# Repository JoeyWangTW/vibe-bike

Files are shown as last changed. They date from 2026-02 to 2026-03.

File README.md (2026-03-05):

# Vibe Bike

**What do humans do while agents work? They bike.**

Turn a broken indoor bike into a smart training station. Track cadence, speed, heart rate, and Claude Code token spend — all on one ESP32 display.

Built as a vibe coding project with Claude Code.

## Features

- **Cadence & speed** from the bike's built-in reed switch sensor
- **Distance tracking** with session auto-detect (start/stop)
- **BLE heart rate** from any Bluetooth heart rate strap
- **Claude Code stats** — live output tokens and message count from your coding sessions
- **SD card logging** — CSV session logs with full ride data
- **3D-printable mount** to attach the display to the bike

## Hardware

| Part | Notes |
|---|---|
| ESP32 CYD (Cheap Yellow Display) | 2.8" ESP32-32E with ILI9341, 240x320px. [Amazon](https://www.amazon.com/dp/B0G1M5XHDL) (or cheaper on AliExpress, search "ESP32-2432S028") |
| Indoor bike with reed switch | Most indoor bikes have a 2-pin magnetic reed switch for cadence. If yours doesn't, any hall effect sensor works |
| BLE heart rate strap | Any strap that advertises BLE Heart Rate Service (UUID 0x180D). Tested with Coospo H808S |
| 10K resistor | Pull-up for the reed switch signal line |
| Micro SD card | For session logging (optional) |
| 3D-printed mount | See `3d-model/` — slots onto a metal plate bracket on the bike |

### Wiring

The reed switch connects to GPIO 35 with a pull-up resistor:

```
3.3V ─── 10K resistor ─── IO35 ─── bike wire 1
GND  ────────────────────────────── bike wire 2
```

No polarity — the reed switch is just an open/close contact.

## Setup

### 1. Install arduino-cli

```bash
# macOS
brew install arduino-cli

# Or see https://arduino.github.io/arduino-cli/installation/
```

### 2. Install ESP32 board support

```bash
arduino-cli config init
arduino-cli config add board_manager.additional_urls https://raw.githubusercontent.com/espressif/arduino-esp32/gh-pages/package_esp32_index.json
arduino-cli core update-index
arduino-cli core install esp32:esp32@3.3.7
```

### 3. Install libraries

```bash
arduino-cli lib install "TFT_eSPI@2.5.43"
arduino-cli lib install "ArduinoJson@7.4.2"
```

The TFT_eSPI library needs its `User_Setup.h` configured for the CYD's ILI9341 SPI pins. See the [display docs](https://www.lcdwiki.com/2.8inch_ESP32-32E_Display) for pin mapping.

### 4. Configure

```bash
cd firmware/bike_dashboard
cp config.example.h config.h
```

Edit `config.h`:

```c
// WiFi (optional — leave empty to skip)
#define WIFI_SSID         "your-wifi"
#define WIFI_PASSWORD     "your-password"

// Claude Code stats server (optional — leave empty to skip)
#define STATS_SERVER_IP   "192.168.1.100"
#define STATS_SERVER_PORT  8888

// BLE heart rate strap name (optional — leave empty to match any HR device)
#define BLE_HR_DEVICE_NAME  "808"
```

All three sections are optional. The dashboard works standalone with just the bike sensor.

### 5. Compile and upload

```bash
# Compile (min_spiffs partition needed for BLE + WiFi)
arduino-cli compile -b esp32:esp32:esp32:PartitionScheme=min_spiffs firmware/bike_dashboard

# Upload (460800 baud — default 921600 fails on CYD boards)
arduino-cli upload -b esp32:esp32:esp32:PartitionScheme=min_spiffs,UploadSpeed=460800 -p /dev/cu.usbserial-1120 firmware/bike_dashboard
```

Your serial port will differ — run `arduino-cli board list` to find it. The CYD uses a CH340 USB-serial chip.

If upload fails with "Failed to connect to ESP32", hold the **BOOT** button on the board while uploading.

### 6. Claude Code stats server (optional)

To show live Claude Code token usage on the display:

```bash
python3 scripts/stats_server.py
```

This reads your local Claude Code session data and serves it over HTTP. The ESP32 polls it every 30 seconds. The server prints the IP and port to put in your `config.h`.

## 3D-Printable Mount

The `3d-model/` directory has OpenSCAD source and ready-to-print STL files:

- **`bike_mount.scad`** — Tray-style case. The board slides in from the front, 4 L-bracket corner spacers hold it at the right depth with space behind for a battery. A slot in the back wall friction-fits onto a metal plate bracket on the bike. USB-C accessible from the bottom.
- **`front_cap.scad`** — Snap-on faceplate with a screen cutout. Covers the PCB edges, shows only the display.

Print with the open face pointing up. No supports needed.

## Project Structure

```
firmware/
  bike_dashboard/         # Main dashboard firmware
    bike_dashboard.ino
    config.example.h      # Template — copy to config.h
  test_ble_hr/            # BLE heart rate test sketch
  test_ble_scan/          # BLE scan test sketch
  test_reed_switch/       # Reed switch test sketch
  hello_world/            # Display test sketch

scripts/
  stats_server.py         # Claude Code stats HTTP bridge

3d-model/
  bike_mount.scad         # Display mount (OpenSCAD source)
  bike_mount.stl          # Ready to print
  front_cap.scad          # Front cap (OpenSCAD source)
  front_cap.stl           # Ready to print
```

## License

MIT

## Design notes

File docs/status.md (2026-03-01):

# Project Status

**Last updated:** 2026-03-01

**Current state:** Phase 3 COMPLETE + HR Zone feature. Full vibe bike dashboard with cadence, speed, distance, BLE heart rate, Claude Code stats tracking, SD logging, and touchscreen HR zone settings.

## Recently Completed

- **HR Zone feature** — touchscreen-enabled heart rate zone settings
  - XPT2046_Bitbang touch on software SPI (IO32/39/25/33, IRQ on IO36)
  - Page system: dashboard ↔ HR zone settings (tap HR block to open)
  - Settings: upper/lower limit +/- (5 bpm steps), on/off toggle, back button
  - Zone indicator: green background in-zone, flashing red out-of-zone
  - NVS persistence via Preferences library (survives reboots)
  - Flash: 1892KB (96% of min_spiffs), 74KB headroom
- **Phase 1** (VB-001 to VB-009): Pulse counting, RPM, speed, distance, TFT dashboard, session management, SD logging
- **Phase 2** (VB-010 to VB-013): BLE heart rate from Coospo H808S chest strap
- **Phase 3** (VB-014 to VB-017): WiFi + Claude Code stats tracking

## Technical Notes

- Partition scheme: `min_spiffs` (BLE+WiFi needs ~1.8MB flash vs 1.3MB default)
- BLE: Uses **built-in ESP32 BLE** (NOT NimBLE — NimBLE 2.3.7 scan returns 0 devices on this board)
- HR strap: Coospo H808S, advertises as "808S 0023713", BLE address `de:5c:38:c5:83:1d`
- Stats tracking reads `~/.claude/stats-cache.json` via local Python HTTP bridge (not Anthropic Admin API, which tracks API billing not Max subscription)
- WiFi and stats tracking are optional — leave `WIFI_SSID` and `STATS_SERVER_IP` empty to disable
- Upload baud: 460800 (921600 causes "chip stopped responding")

## In Progress

- (Nothing currently in progress)

## Up Next

- Upload and test touch calibration (first boot will prompt calibration via Serial)
- Test HR zone settings page on device
- Physical mounting of display on bike
- Test full end-to-end: pedal + HR strap + stats server + HR zones

## Blockers

- (none)

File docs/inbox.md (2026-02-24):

# Inbox

Action items from co-founder discussions, standups, and meetings appear here.
Mark items as `[SEEN]` after reading them.

---

## From VP Cadence Cole Planning Session (2026-02-24)

- [x] [DONE] Probe the bike's 2-pin connector with a multimeter. Result: reed switch, 1 pulse/rev, no polarity.
- [ ] Power up the ESP32 display board and verify it works. Try a simple TFT_eSPI example sketch.
- [ ] [SEEN] Test IO35 with a simple digitalRead — confirmed plan: IO35 with 10K pull-up. Use `firmware/test/test_reed_switch.cpp` to verify.
- [ ] Measure the physical mounting: how will the display attach where the old monitor was? Any 3D printing needed or can you use zip ties / velcro for now?
- [ ] Check your chest HR strap model — confirm it supports standard BLE Heart Rate Service (UUID 0x180D). Most Garmin/Polar/Wahoo straps do.

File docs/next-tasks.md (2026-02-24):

# Prioritized Tasks

## Completed
- ~~**VB-001:** Probe 2-pin connector~~ — reed switch, 1 pulse/rev
- ~~**VB-002:** Test GPIO~~ — IO35 confirmed
- ~~**VB-003:** Wire bike sensor~~ — IO35 + 10K pull-up + GND

## Next Up (Phase 1 Firmware)

1. **VB-006:** Set up PlatformIO project, configure TFT_eSPI for the ILI9341 board, flash "Hello World"
2. **VB-004:** Implement interrupt-driven pulse counter (use `test_reed_switch.cpp` to verify hardware first)
3. **VB-005:** Calculate speed and distance from RPM
4. **VB-007:** Build dashboard UI v1 (RPM, speed, distance, time)
5. **VB-008:** Auto-detect session start/stop
6. **VB-009:** Log session data to SD card

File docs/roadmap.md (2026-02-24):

# Vibe Bike Roadmap

## Vision

**"What do humans do while agents work? Joey bikes."**

Vibe Bike is a personal fitness-meets-vibe-coding dashboard. It turns a broken indoor bike into a smart training station that tracks physical activity AND coding productivity in one place. The final form is a "vibe coding bike session" — pedal, monitor heart rate, and watch your Claude Code token spend all on a single ESP32 display mounted where the old monitor used to be.

The deeper message: while AI agents handle the code, you invest in yourself. Get healthier, stay sharp, and still see exactly what your agents are burning through.

## Hardware

| Component | Details |
|---|---|
| Indoor bike | Broken monitor removed; 2-pin connector exposed (likely reed switch for cadence/speed) |
| Display/MCU | 2.8" ESP32-32E (ILI9341V), 240x320px, ESP32-D0WD-V3 dual-core @ 240MHz |
| Connectivity | WiFi 802.11b/g/n, Bluetooth 4.2 + BLE |
| Heart rate | Chest strap (BLE-compatible, likely ANT+ too) |
| Free GPIOs | IO27 (if SPI peripheral unused), IO35 (input-only) — very limited |

---

## Phase 1: Bike Data on Screen (MVP)

**Goal:** Read cadence/speed from the bike's 2-pin connector and display it on the ESP32 screen.

**Timeline:** 1-2 weeks

### Milestones

- [ ] **1.1 — Hardware investigation**
  - Probe the 2-pin connector with a multimeter to determine signal type (reed switch pulses vs. analog vs. hall effect)
  - Identify a usable GPIO on the ESP32 board (IO27 or IO35 are candidates)
  - Wire the 2-pin connector to the ESP32 with appropriate pull-up/pull-down resistor

- [ ] **1.2 — Signal capture firmware**
  - Write interrupt-driven pulse counter on ESP32 (Arduino or ESP-IDF)
  - Calculate RPM from pulse timing
  - Estimate speed/distance using assumed wheel circumference

- [ ] **1.3 — Display UI v1**
  - Render a simple dashboard on the ILI9341: current RPM, speed, distance, elapsed time
  - Use TFT_eSPI or LovyanGFX library for rendering
  - Keep it clean — big numbers, easy to read while pedaling

- [ ] **1.4 — Session persistence**
  - Log session data to ESP32's onboard SD card (CSV format)
  - Start/stop session with a simple trigger (e.g., first pedal stroke starts, 30s idle stops)

### Key Risks
- **GPIO scarcity:** The ESP32 board has very few free pins. IO35 is input-only (fine for reading pulses). IO27 may conflict with SPI. Need to verify on actual hardware.
- **Signal type unknown:** The 2-pin connector might be a simple reed switch (most likely), but could also be a hall sensor with specific voltage needs.
- **No physical button:** Starting/stopping sessions may need to be auto-detected from pedal activity.

---

## Phase 2: Heart Rate Monitor

**Goal:** Connect BLE chest strap and add heart rate to the dashboard.

**Timeline:** 1-2 weeks (after Phase 1)

### Milestones

- [ ] **2.1 — BLE heart rate pairing**
  - Implement BLE client on ESP32 to scan and connect to heart rate strap
  - Use standard Heart Rate Service (UUID 0x180D) / Heart Rate Measurement Characteristic (0x2A37)
  - Handle reconnection gracefully

- [ ] **2.2 — Display UI v2**
  - Add heart rate (current BPM) to the dashboard
  - Add heart rate zone indicator (zone 1-5 based on estimated max HR)
  - Show connection status for the HR strap

- [ ] **2.3 — Combined session logging**
  - Merge cadence + HR data into session logs
  - Timestamp alignment between bike pulses and HR readings

### Key Risks
- **BLE + WiFi coexistence:** ESP32 shares the radio between WiFi and BLE. If both are active, performance may degrade. Phase 2 is BLE-only so this is fine, but matters for Phase 3.
- **HR strap compatibility:** Most chest straps support standard BLE HR profile, but some cheaper ones may not.

---

## Phase 3: Vibe Coding Dashboard

**Goal:** Track Claude Code token usage alongside bike + HR data. The ultimate "vibe coding session" view.

**Timeline:** 2-4 weeks (after Phase 2)

### Milestones

- [ ] **3.1 — Claude Code token tracking**
  - Build a lightweight local service (Python or Node) that monitors Claude Code token usage
  - Options: parse Claude Code logs, use API usage endpoints, or intercept billing data
  - Expose a simple HTTP endpoint on the local machine for the ESP32 to poll

- [ ] **3.2 — WiFi data sync**
  - Connect ESP32 to local WiFi
  - Poll the token tracking endpoint periodically (every 30s)
  - Handle WiFi + BLE coexistence (may need to time-slice or alternate)

- [ ] **3.3 — Display UI v3 — Final Form**
  - Combined dashboard: cadence, speed, distance, time, HR, HR zone, tokens used, cost
  - Session summary screen at end of ride
  - Maybe: a fun "vibe score" combining physical effort + code productivity

- [ ] **3.4 — Session history and trends**
  - Daily session logs: duration, distance, avg HR, tokens used
  - Upload session data to a simple local DB or flat files for trend viewing
  - Optional: a simple web dashboard for historical data

### Key Risks
- **Token tracking API:** Claude Code may not expose usage data in a clean, parseable way. May need to get creative with log parsing.
- **WiFi + BLE conflict:** Both use the same radio. May need to alternate connections or use BLE for HR and WiFi in bursts.
- **Scope creep:** This phase could grow endlessly. Keep the MVP tight: just show tokens used in current session.

---

## Future Ideas (Post-V1)

- **Leaderboard / streaks:** Track daily riding streaks and coding output
- **Agent health check:** Show which Claude Code tasks are running while you ride
- **Calorie-to-token ratio:** A fun metric — how many calories per 1K tokens?
- **OTA updates:** Push firmware updates over WiFi so you don't have to dismount
- **3D-printed enclosure:** Mount the display cleanly where the old monitor was

---

## Technical Stack

| Layer | Technology |
|---|---|
| Firmware | Arduino framework on ESP32 (PlatformIO recommended) |
| Display | TFT_eSPI or LovyanGFX library for ILI9341 |
| BLE | ESP32 NimBLE or Arduino BLE library |
| Token tracking | Python/Node local service with HTTP API |
| Data storage | SD card (on-device), local files or SQLite (on host) |

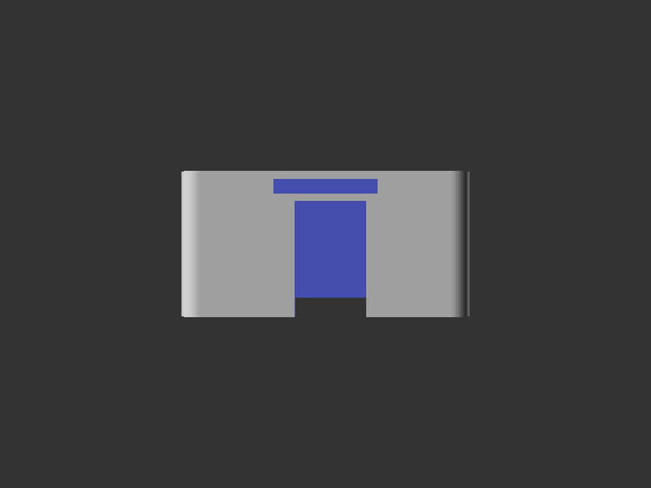
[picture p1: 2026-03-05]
3d-model/render_front.png

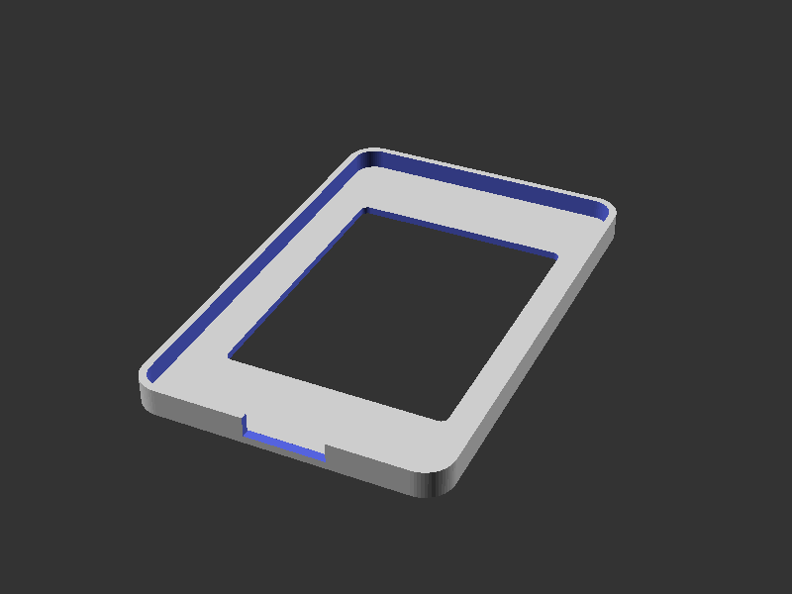
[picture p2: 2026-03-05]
3d-model/cap_angle_view.png

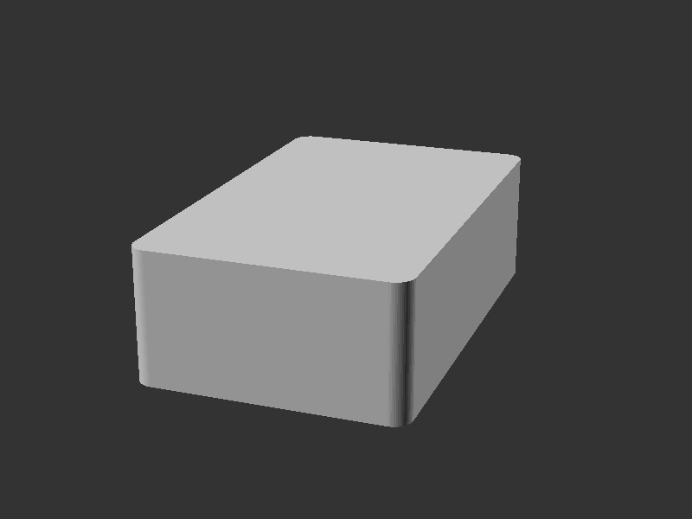
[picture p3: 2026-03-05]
3d-model/render_bottom.png

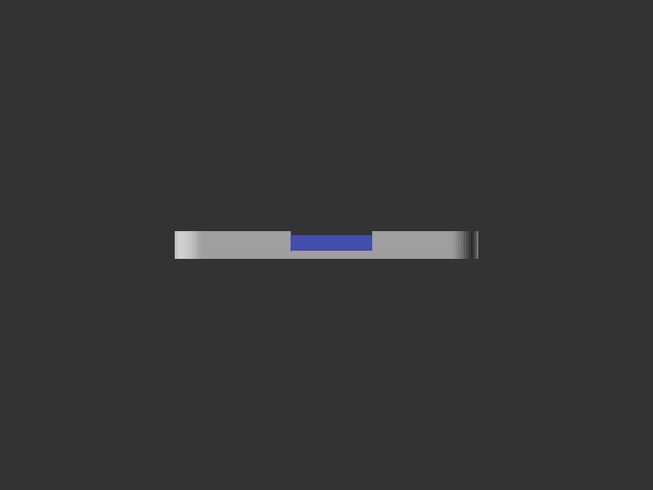
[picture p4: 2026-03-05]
3d-model/cap_front_view.png

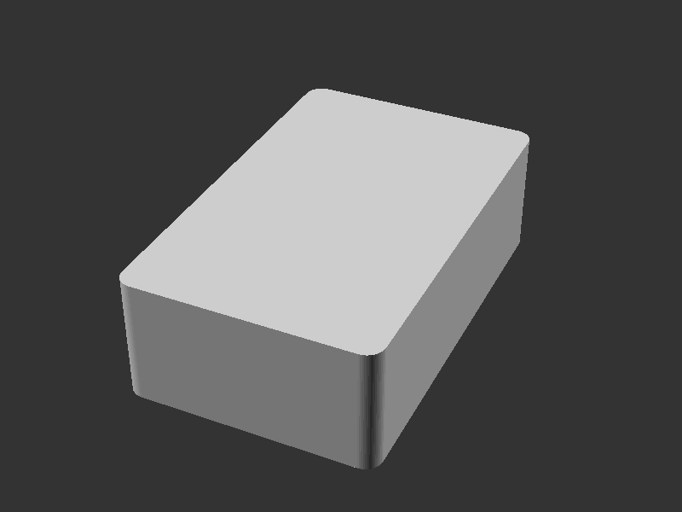
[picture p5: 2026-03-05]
3d-model/render_back_angle.png

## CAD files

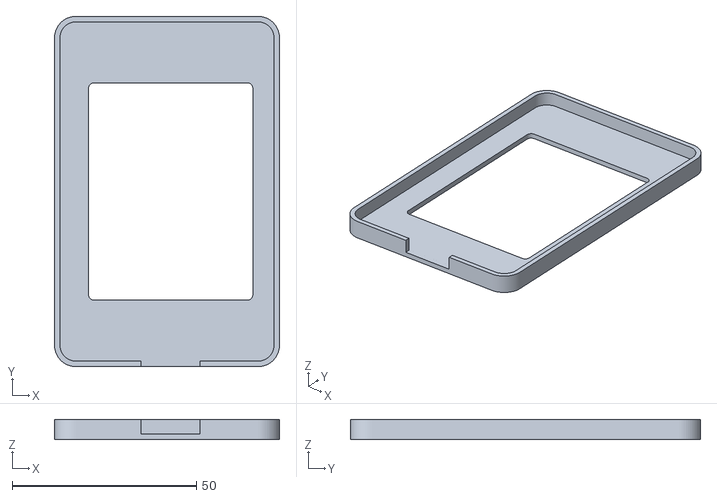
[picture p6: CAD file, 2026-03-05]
3d-model/front_cap.stl
61.1 x 95.1 x 5.50

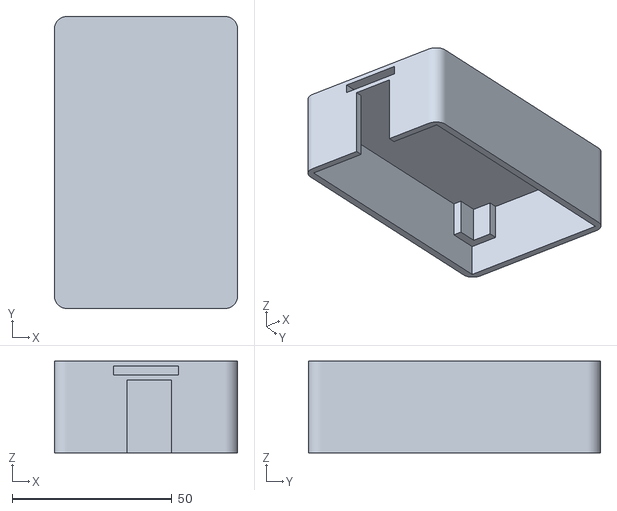
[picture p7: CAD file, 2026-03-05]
3d-model/bike_mount.stl
57.5 x 91.5 x 28.8

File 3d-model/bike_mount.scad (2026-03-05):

/*
 * Vibe Bike Display Mount v4.1
 * ============================
 * Coords: X=width, Y=height(bottom->top), Z=depth(front->back)
 * Board slides in from front (Z=0). Screen faces out.
 * 4 L-bracket spacers behind board create battery space.
 * Plate slot and USB on bottom (Y=0).
 *
 * Front view (looking along Z into tray):
 *   ┌─────────────────────┐
 *   │ ┌──┐           ┌──┐ │  <- brackets (top corners)
 *   │ └──┤           ├──┘ │
 *   │    │  board    │    │
 *   │    │  slides   │    │
 *   │    │  in here  │    │
 *   │ ┌──┤           ├──┐ │
 *   │ └──┘           └──┘ │  <- brackets (bottom corners)
 *   └─────────────────────┘
 *
 * Print: Open side (Z=0) facing up.
 */

$fn = 60;

// ================================================================
//  MEASUREMENTS
// ================================================================

BOARD_W      = 50.0;    // PCB width (X)
BOARD_H      = 86.0;    // PCB height (Y)
BOARD_T      = 10.6;    // total thickness (Z, depth when slid in)

PLATE_W      = 20.0;    // metal plate width
PLATE_T      = 2.5;     // metal plate thickness

// ================================================================
//  DESIGN PARAMETERS
// ================================================================

WALL         = 2.5;     // wall thickness
TOL          = 0.2;     // tolerance (gap between board back and bracket face)
BATT_SPACE   = 12.0;    // space behind board for battery/wires (Z)
BACK_WALL    = 6.0;     // back wall thickness (holds plate slot)
SLOT_H       = 25.0;    // plate slot engagement height (Y)
USB_W        = 14.0;    // USB-C slot width
CORNER_R     = 4.0;     // outer corner radius

// Corner brackets (in X-Y plane, extend along Z)
BOARD_GAP    = 0.25;    // clearance between board edge and cavity wall (friction fit)
CONN_EXTRA   = 2.0;     // extra right-side clearance for IO35 connector + wires
BRACKET_W    = 3.0;     // bracket arm width (> BOARD_GAP so it overlaps under board)
BRACKET_ARM  = 10.0;    // bracket arm length along wall

// ================================================================
//  COMPUTED
// ================================================================

inner_w    = BOARD_W + BOARD_GAP * 2 + CONN_EXTRA; // 52.5 (extra on right for connector)
inner_h    = BOARD_H + BOARD_GAP * 2;           // 86.5
cavity_d   = BOARD_T + TOL + BATT_SPACE;        // 22.8

frame_w    = inner_w + WALL * 2;                // 57.5
frame_h    = inner_h + WALL * 2;                // 91.5
frame_d    = cavity_d + BACK_WALL;              // 28.8

// Board position (shifted right in cavity, extra gap on left/low-X = screen-right for connector)
board_x    = WALL + BOARD_GAP + CONN_EXTRA;     // 4.75
board_y    = WALL + BOARD_GAP;                  // 2.75

// Plate slot (centered X, in back wall)
slot_w     = PLATE_W + TOL * 2;
slot_t     = PLATE_T + TOL * 2;
slot_z     = frame_d - BACK_WALL + (BACK_WALL - slot_t) / 2;

// ================================================================
//  HELPERS
// ================================================================

module rounded_box(w, h, d, r) {
    translate([r, r, 0])
        minkowski() {
            cube([w - r*2, h - r*2, d]);
            cylinder(r=r, h=0.001);
        }
}

// ================================================================
//  MODEL
// ================================================================

module mount() {
    difference() {
        // ---- Build body + brackets, then cut USB last ----
        union() {
            difference() {
                // Solid body (rounded corners in X-Y)
                rounded_box(frame_w, frame_h, frame_d, CORNER_R);

                // Cavity (open at front Z=0, board slides in here)
                translate([WALL, WALL, -1])
                    cube([inner_w, inner_h, cavity_d + 1]);

                // Plate slot (in back wall, open at bottom Y=0)
                translate([(frame_w - slot_w) / 2, -1, slot_z])
                    cube([slot_w, SLOT_H + WALL + 1, slot_t]);
            }

            // 4 L-bracket spacers (behind board, in battery zone)
            bz = BOARD_T + TOL;   // bracket start Z (just behind board)
            bd = BATT_SPACE;       // bracket depth along Z

            // Bottom-left
            translate([WALL, WALL, bz]) {
                cube([BRACKET_ARM, BRACKET_W, bd]);
                cube([BRACKET_W, BRACKET_ARM, bd]);
            }

            // Bottom-right
            translate([WALL + inner_w, WALL, bz])
                mirror([1, 0, 0]) {
                    cube([BRACKET_ARM, BRACKET_W, bd]);
                    cube([BRACKET_W, BRACKET_ARM, bd]);
                }

            // Top-left
            translate([WALL, WALL + inner_h, bz])
                mirror([0, 1, 0]) {
                    cube([BRACKET_ARM, BRACKET_W, bd]);
                    cube([BRACKET_W, BRACKET_ARM, bd]);
                }

            // Top-right
            translate([WALL + inner_w, WALL + inner_h, bz])
                mirror([1, 0, 0]) mirror([0, 1, 0]) {
                    cube([BRACKET_ARM, BRACKET_W, bd]);
                    cube([BRACKET_W, BRACKET_ARM, bd]);
                }
        }

        // USB-C slot (cut LAST so it goes through wall + brackets)
        // Centered on board (not frame, since cavity is asymmetric)
        translate([board_x + (BOARD_W - USB_W) / 2, -0.01, 0])
            cube([USB_W, board_y + 5, cavity_d]);
    }
}

// ================================================================
//  RENDER
// ================================================================

mount();

// ================================================================
//  VISUALIZATION  (uncomment to check fit)
// ================================================================

// Board (slid in from front):
// color("green", 0.25)
//     translate([board_x, board_y, 0])
//         cube([BOARD_W, BOARD_H, BOARD_T]);

// Metal plate:
// color("silver", 0.3)
//     translate([(frame_w - PLATE_W)/2, -20, slot_z + TOL])
//         cube([PLATE_W, SLOT_H + 25, PLATE_T]);

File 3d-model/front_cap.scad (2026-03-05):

/*
 * Vibe Bike Display Mount - Front Cap v1.0
 * =========================================
 * Slides over front of mount to cover PCB edges,
 * with a cutout showing only the screen.
 *
 * Coords: X=width, Y=height, Z=depth
 *   Z=0 = visible front face (print this on bed)
 *   Z+  = lip extends backward toward mount
 *
 * Front view:
 *   ┌───────────────────────────┐
 *   │                           │
 *   │   ┌───────────────────┐   │
 *   │   │                   │   │
 *   │   │   screen cutout   │   │
 *   │   │                   │   │
 *   │   └───────────────────┘   │
 *   │                           │
 *   └───────────────────────────┘
 *
 * Print: Front face (Z=0) on bed, lip pointing up.
 */

$fn = 60;

// ================================================================
//  MOUNT DIMENSIONS (must match bike_mount.scad)
// ================================================================

BOARD_W      = 50.0;
BOARD_H      = 86.0;
WALL         = 2.5;
BOARD_GAP    = 0.25;
CONN_EXTRA   = 2.0;     // extra right-side clearance (must match bike_mount.scad)
CORNER_R     = 4.0;
USB_W        = 14.0;

inner_w      = BOARD_W + BOARD_GAP * 2 + CONN_EXTRA;
inner_h      = BOARD_H + BOARD_GAP * 2;
frame_w      = inner_w + WALL * 2;           // 55.5
frame_h      = inner_h + WALL * 2;           // 91.5

board_x      = WALL + BOARD_GAP + CONN_EXTRA; // 4.75 (extra gap on low-X = screen-right for connector)
board_y      = WALL + BOARD_GAP;             // 2.75

// ================================================================
//  SCREEN DIMENSIONS (ES3C28P datasheet)
// ================================================================

SCREEN_VA_W  = 43.60;    // visible area width
SCREEN_VA_H  = 58.05;    // visible area height

// Screen centered on board
screen_x     = board_x + (BOARD_W - SCREEN_VA_W) / 2;   // 5.95
screen_y     = board_y + (BOARD_H - SCREEN_VA_H) / 2;   // 16.725

// ================================================================
//  CAP DESIGN PARAMETERS
// ================================================================

CAP_T        = 1.5;      // plate thickness
LIP_T        = 1.5;      // lip wall thickness
LIP_D        = 4.0;      // lip depth (wraps back over mount)
FIT_TOL      = 0.3;      // clearance for cap to slide onto mount
SCREEN_M     = 0.5;      // margin around screen cutout
SCREEN_R     = 1.5;      // screen cutout corner radius

// ================================================================
//  COMPUTED
// ================================================================

// Offset from cap origin to mount frame origin
offset       = LIP_T + FIT_TOL;

// Cap outer dimensions
cap_w        = frame_w + offset * 2;         // 59.1
cap_h        = frame_h + offset * 2;         // 95.1
cap_r        = CORNER_R + offset;            // 5.8

// Lip inner pocket (matches mount frame + tolerance)
lip_inner_w  = frame_w + FIT_TOL * 2;
lip_inner_h  = frame_h + FIT_TOL * 2;
lip_inner_r  = CORNER_R + FIT_TOL;

// Screen cutout (in cap coordinates)
cut_w        = SCREEN_VA_W + SCREEN_M * 2;   // 44.6
cut_h        = SCREEN_VA_H + SCREEN_M * 2;   // 59.05
cut_x        = offset + screen_x - SCREEN_M; // 7.25
cut_y        = offset + screen_y - SCREEN_M; // 18.025

// USB cable clearance in bottom lip (centered on board, not frame)
usb_cut_w    = USB_W + 2;
usb_cut_x    = offset + board_x + (BOARD_W - usb_cut_w) / 2;

// ================================================================
//  HELPERS
// ================================================================

module rounded_box(w, h, d, r) {
    translate([r, r, 0])
        minkowski() {
            cube([w - r*2, h - r*2, d]);
            cylinder(r=r, h=0.001);
        }
}

module rounded_rect(w, h, r) {
    translate([r, r])
        minkowski() {
            square([w - r*2, h - r*2]);
            circle(r=r);
        }
}

// ================================================================
//  MODEL
// ================================================================

module cap() {
    difference() {
        union() {
            // Front plate (Z=0 to CAP_T)
            rounded_box(cap_w, cap_h, CAP_T, cap_r);

            // Lip (Z=CAP_T to CAP_T+LIP_D, wraps around mount frame)
            translate([0, 0, CAP_T])
                difference() {
                    rounded_box(cap_w, cap_h, LIP_D, cap_r);
                    translate([LIP_T, LIP_T, -1])
                        rounded_box(lip_inner_w, lip_inner_h, LIP_D + 2, lip_inner_r);
                }
        }

        // Screen cutout (through plate)
        translate([cut_x, cut_y, -1])
            linear_extrude(CAP_T + 2)
                rounded_rect(cut_w, cut_h, SCREEN_R);

        // USB cable clearance (notch in bottom lip)
        translate([usb_cut_x, -0.01, CAP_T - 0.01])
            cube([usb_cut_w, offset + 0.02, LIP_D + 0.02]);
    }
}

// ================================================================
//  RENDER
// ================================================================

cap();

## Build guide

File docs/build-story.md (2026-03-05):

# How We Built the Vibe Bike: A Human + Claude Code Story

**What do humans do while agents work? Joey bikes.**

This is the story of how a broken indoor bike became a smart training dashboard — built over five late nights by one person and an AI coding partner. It's a story about vibe coding at its most literal: building a thing that tracks your biking *and* your AI's coding, on a single screen, with Claude Code doing most of the typing.

---

## The Starting Point: A Broken Bike and a Spare Screen

The project began with two things sitting around unused:

1. An indoor exercise bike with a dead monitor. The old display was gone, but there was a 2-pin connector dangling from the frame — a mystery signal from whatever sensor the original monitor used.
2. A "Cheap Yellow Display" (CYD) — a $12 ESP32 dev board with a 2.8" touchscreen, WiFi, Bluetooth, and an SD card slot. The kind of board that sits in a drawer until you find the right project for it.

The idea was simple: mount the screen where the old monitor was, read the bike sensor, and build a dashboard. But the ambition grew. What if it also showed your heart rate? What if it showed how many tokens Claude Code was burning while you pedaled?

The deeper message: while AI agents handle the code, you invest in yourself. A fitness dashboard that also monitors your AI's productivity.

---

## Night 1: The Sprint (Feb 24, 2am)

### Planning with "VP Cadence Cole"

The first session started with planning. Joey set up the project structure — a PRD with user stories, a roadmap, work docs — and framed the planning as a session with the fictional "VP Cadence Cole." (The VP of Cadence. For a bike project. It's a vibe.)

Five action items went into the inbox, the kind of things Claude Code can't do: probe the 2-pin connector with a multimeter, figure out the GPIO situation on the board, check the heart rate strap model. Hardware investigation, done by hand.

The results: the mystery connector was a reed switch (a magnet on the pedal passes by a sensor once per revolution — the simplest possible signal). IO35 on the ESP32 was free and input-capable. A 10K pull-up resistor and two wires later, the bike was connected.

### Unleashing Ralph

With the hardware wired up, Joey launched "Ralph" — an autonomous agent loop. Ralph is a bash script that feeds a prompt to Claude Code (or Amp), telling it to: read the PRD, find the highest-priority incomplete story, implement it, commit, repeat. One story per iteration, one commit per story.

What happened next was fast. Seven commits in 21 minutes:

| Time | Story | What Happened |
|---|---|---|
| 2:06 | Setup | Project scaffolding, docs, test sketches |
| 2:08 | VB-004 | Interrupt-driven pulse counter with debounce and RPM smoothing |
| 2:12 | VB-005 | Speed and distance calculation from RPM |
| 2:18 | VB-006 | "Hello World" on the display — first pixels lit up |
| 2:21 | VB-007 | Full dashboard UI: big RPM numbers, color-coded metrics |
| 2:23 | VB-008 | Session state machine: auto-detect start/pause/stop |
| 2:27 | VB-009 | SD card logging with CSV session files |

Phase 1 complete. In 21 minutes, Ralph went from "we have a reed switch" to a working bike computer with a color dashboard and data logging. The firmware grew from nothing to 611 lines across that sprint.

### What worked

The Ralph loop was a perfect fit for this kind of work — well-scoped user stories, a clear build/verify cycle (`arduino-cli compile`), and no external dependencies to break. Each story built cleanly on the last. Claude Code could read the previous code, understand the patterns, and extend them.

The key insight: the human did the *hardware* work (probing, wiring, testing signals), then handed off the *firmware* work to the agent. Each doing what they're good at.

---

## Night 2: The Ambitious Commit (Feb 25, 11pm)

### Two Phases in One Shot

The next session went big. Instead of one story at a time, the commit log shows **eight user stories landed in a single commit** — all of Phase 2 (BLE heart rate) and Phase 3 (WiFi + token tracking) together.

This was Claude Code writing nearly 600 new lines: NimBLE for Bluetooth heart rate, WiFiClientSecure for HTTPS to the Anthropic Admin API, ArduinoJson for parsing responses, a complete display redesign to fit all the new metrics, and combined session logging. The firmware nearly doubled from 611 to 1,191 lines.

It compiled. It got committed. On paper, the project was done.

### The choices made

Two key technical decisions were baked into this commit:

1. **NimBLE** for BLE — chosen because it's lighter than the built-in ESP32 BLE library
2. **Anthropic Admin API** for token tracking — call the billing API to see how many tokens Claude Code is using

Both seemed reasonable. Both were wrong.

---

## Night 3: The Reckoning (Feb 25-27, hardware time)

### "NimBLE doesn't work on this board"

When the firmware was actually uploaded to the physical board (460800 baud — the default 921600 crashed the chip, first lesson), the BLE heart rate feature was dead. NimBLE's scan returned zero devices. Direct connect crashed.

Joey switched to the built-in ESP32 BLE library and ran a scan: **42 devices found**, including the heart rate strap, immediately. The Coospo H808S showed up as "808S 0023713" and started sending heart rate data within minutes.

The fix was a full rewrite of the BLE code — ripping out NimBLE and replacing it with the heavier but actually-functional built-in library. This is the kind of problem that only surfaces on real hardware. Claude Code had written perfectly correct NimBLE code; the library just didn't work on this specific ESP32 variant.

**Lesson:** Code that compiles isn't code that works. The gap between "it compiles" and "it runs on the hardware" is where the real debugging lives. An AI can write firmware all day, but someone has to plug it in.

### "The Admin API tracks the wrong thing"

The second surprise was more subtle. The Anthropic Admin API was integrated, HTTPS was working, tokens were being fetched... but the numbers didn't match what Joey was seeing in Claude Code.

It turned out the Admin API tracks **API billing** — tokens consumed by applications calling the API. Joey was on Claude Max (a subscription), where there's no per-token billing. The usage data he wanted — tokens and messages from Claude Code sessions — lives in a completely different place: a local file at `~/.claude/stats-cache.json`.

The pivot was clean:
- Ripped out `WiFiClientSecure` (HTTPS) entirely
- Wrote a 50-line Python script (`stats_server.py`) that reads the local stats file and serves it over HTTP
- Replaced the firmware's HTTPS client with a simple HTTP GET to `http://<mac-ip>:8888/stats`
- Changed the display from TOKENS + COST to TOKENS + MSGS (no per-token cost on Max)

This actually *saved* flash space — HTTPS is expensive on an ESP32. The firmware went from fighting flash limits to having a bit more breathing room (briefly).

### What this phase taught us

These two debugging sessions — BLE library swap and API pivot — were the most *human* parts of the entire project. Claude Code wasn't in the loop for the discovery. Joey was the one staring at a serial monitor showing "0 devices found," the one realizing the API numbers didn't add up. The fixes were collaborative — Joey identified the problems, Claude Code wrote the new implementations — but the diagnosis was all human.

This is also the phase where the CLAUDE.md file became truly valuable. After each discovery, the instructions were updated:

> BLE library: **Built-in ESP32 BLE** (NOT NimBLE — NimBLE 2.3.7 doesn't work on this board, scan returns 0 devices)

> Upload speed: 460800 baud (default 921600 fails on this board)

These "NOT X" annotations are scars. They exist because someone tried X first, and they're written so that the next Claude Code session (or the next developer) doesn't repeat the mistake.

---

## Night 4: Going Physical (Mar 1, 1am)

### 3D-Printed Mount

With the firmware stable, the project shifted to the physical world. Claude Code designed a 3D-printable mount in OpenSCAD — a tray-style case where the board slides in from the front, with L-bracket corner spacers and a slot that friction-fits onto the bike's metal plate bracket. A snap-on front cap covers the PCB edges and shows only the screen.

This was an interesting moment: an AI designing a physical object for a specific bike, based on measurements Joey provided. The mount needed to account for the board dimensions (50x86mm), leave space behind for a battery, keep the USB-C port accessible from the bottom, and attach to the bike's existing bracket.

### Touchscreen HR Zones

The final major feature was touchscreen support. The CYD has a resistive touchscreen (XPT2046), but all three SPI buses were already spoken for (display on HSPI, SD card on VSPI). Claude Code's solution: bit-bang a software SPI interface on the remaining GPIOs.

This unlocked a settings page — tap the heart rate area on the dashboard to open HR zone settings, with +/- buttons for upper and lower limits. The zone indicator flashes the screen border red when you're outside your target heart rate, green when you're in it. Settings persist across reboots via the ESP32's NVS (non-volatile storage).

The firmware hit 1,549 lines and 96% of available flash. Only 74KB of headroom remaining on the ESP32's min_spiffs partition.

---

## The Final Product

What started as a broken bike and a spare screen became:

- **Cadence and speed** from the original reed switch sensor
- **Distance tracking** with automatic session detection
- **BLE heart rate** from a Bluetooth chest strap
- **Claude Code stats** — live tokens and messages from your coding sessions
- **SD card logging** — CSV files with full ride + coding data
- **Touchscreen HR zones** — set targets, get visual feedback
- **3D-printed mount** — designed to slot onto the bike

All running on a $12 ESP32 board with a 2.8" screen, at 96% flash capacity.

---

## What We Learned About Building Together

### The Human-AI Division of Labor

The pattern that emerged wasn't "AI writes all the code" — it was more nuanced:

| Human | AI |
|---|-----|
| Probed the reed switch with a multimeter | Wrote the interrupt-driven pulse counter |
| Wired GPIO35 with a pull-up resistor | Designed the display layout |
| Discovered NimBLE doesn't work on this board | Rewrote BLE code using the working library |
| Realized the Admin API tracks the wrong data | Built the local stats server + firmware client |
| Gave feedback on RPM label placement | Moved the label |
| Provided bike bracket measurements | Designed the 3D mount in OpenSCAD |
| Tested on hardware, reported bugs | Fixed bugs, iterated on code |

Joey handled everything that required physical access, domain knowledge, or judgment calls. Claude Code handled everything that required writing, refactoring, or maintaining large amounts of code. The handoff points were clean because the project documentation (CLAUDE.md, worklog, PRD) served as a shared memory between sessions.

### Ralph: Autonomous Agent Loops Work for Well-Scoped Tasks

The Ralph loop — an autonomous agent churning through user stories — was remarkably effective for Phase 1. Seven stories in 21 minutes, each building on the last. The key ingredients:

1. **Clear acceptance criteria** in the PRD for each story
2. **A verifiable build step** (`arduino-cli compile`)
3. **Incremental complexity** — each story extended the previous one
4. **No external dependencies** to break between iterations

Where it broke down: Phase 2 and 3 were attempted as one big batch, and the code that came out compiled but didn't run. The agent couldn't test on real hardware, and two of its technology choices (NimBLE, Admin API) were wrong for this specific context.

### CLAUDE.md as Living Documentation

The most valuable artifact might be the CLAUDE.md file itself. It started as an optimistic plan and evolved into hard-won truth:

- **Version 1** (day 1): "NimBLE — lighter than Arduino BLE"
- **Version 2** (after Phase 2+3): "NimBLE-Arduino 2.3.7"
- **Version 3** (after debugging): "Built-in ESP32 BLE (NOT NimBLE — NimBLE 2.3.7 doesn't work on this board, scan returns 0 devices)"

Each version reflects increasing contact with reality. The "NOT X" pattern — explicitly documenting what doesn't work — turned out to be one of the most useful things in the file. It's a form of institutional memory: not just "here's how to do it" but "here's what we already tried that failed."

### The 2am Pattern

Every commit was made between 1am and 3am. This was a night-owl project, built in the quiet hours when the house is asleep and there's nothing to do but ride a bike and watch Claude Code work. There's something fitting about that — the whole premise is "what do you do while agents work?" and the answer, apparently, is "stay up way too late tinkering."

---

## By the Numbers

| Metric | Value |
|---|---|
| Total time span | 5 days (3 coding sessions) |
| Commits | 11 |
| Lines of firmware | 1,549 |
| User stories completed | 18 |
| Flash usage | 96% (1,892 KB of 1,966 KB) |
| BLE libraries tried | 2 (NimBLE failed, built-in worked) |
| API approaches tried | 2 (Admin API wrong target, local stats server worked) |
| Major pivots | 2 |
| 3D models designed | 2 (mount + front cap) |
| Test sketches written | 4 (reed switch, BLE HR, BLE scan, touch) |
| Hours of the day commits were made | 1am - 3am, exclusively |

---

*Built by Joey Wang and Claude Code, February-March 2026.*

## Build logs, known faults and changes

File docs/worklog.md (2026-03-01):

# Work Log

## 2026-02-24 - Project created

- Initial project setup
- Created project directory and documentation structure

## 2026-02-24 - VP Cadence Cole Planning Session

- Refined vision: "What do humans do while agents work? Joey bikes."
- Researched ESP32-32E display board specs (lcdwiki.com) — identified IO35 and IO27 as available GPIOs
- Created 3-phase roadmap: bike data (MVP) -> heart rate -> vibe coding dashboard
- Wrote 9 user stories for Phase 1 (VB-001 through VB-009)
- Updated CLAUDE.md with vision, hardware specs, pin mapping, and project conventions
- Updated HQ projects.json with vision statement
- Populated inbox with 5 hardware investigation action items for Joey

## 2026-02-24 - Hardware Investigation Complete

- VB-001: Probed 2-pin connector — confirmed reed switch, 1 pulse per revolution, no wire polarity
- VB-002: GPIO decision — IO35 (input-only) with 10K pull-up resistor to 3.3V
- VB-003: Wiring plan: reed switch wire 1 → IO35, wire 2 → GND (either wire to either pin)
- Created `firmware/test/test_reed_switch.cpp` — hardware verification script
- All hardware stories complete, firmware development unblocked

## 2026-02-24 - Switched to arduino-cli, Ralph Loop launched

- Switched build toolchain from PlatformIO to **arduino-cli** (already installed: ESP32 core 3.3.7, TFT_eSPI 2.5.43)
- Updated CLAUDE.md, prd.json (VB-006), and .claude/settings.json with arduino-cli commands
- Created Arduino sketch at `firmware/test_reed_switch/test_reed_switch.ino` — compiles successfully
- CYD detected at `/dev/cu.usbmodem2101` (may need BOOT button for upload)
- Initiated autonomous work session via `/tst:project-work`
- Stories to complete: 6 (VB-004 through VB-009)
- Starting with: VB-006 — Set up Arduino CLI project and display Hello World

## 2026-02-24 - VB-006: Display Hello World

- Configured TFT_eSPI `User_Setup.h` for ESP32-32E board (was incorrectly set for ESP32-S3)
  - Driver: ILI9341_2_DRIVER, SPI port: HSPI, pins: CS=15, DC=2, SCLK=14, MOSI=13, MISO=12, BL=21
  - SPI frequency: 55MHz, backlight HIGH = on
- Created `firmware/hello_world/hello_world.ino` — display test sketch
  - Shows "VIBE BIKE" title, "Hello World!", board info, and pin mapping
  - Turns on backlight via IO21, portrait orientation (240x320)
- Compiles cleanly: 330KB flash (25%), 22KB RAM (6%)
- Existing pulse_counter sketch still compiles with updated User_Setup.h

## 2026-02-24 - VB-007: Dashboard UI v1

- Created `firmware/bike_dashboard/bike_dashboard.ino` — combines pulse counter + TFT display
- Layout (240x320 portrait):
  - Title bar: "VIBE BIKE" in dark teal
  - RPM: huge 7-segment font, cyan, centered
  - Speed + Distance: two-column layout, green + yellow, font 4
  - Elapsed time: orange, font 6, mm:ss format
  - Status bar: PEDALING/STOPPED/READY + revolution count
- Dirty-region updates: only redraws values that changed (prev value tracking)
- 2Hz display refresh rate matching serial output
- Color scheme: dark background, high-contrast colored values per metric
- Compiles: 334KB flash (25%), 23KB RAM (7%)

## 2026-02-24 - VB-008: Auto-detect session start and stop

- Added session state machine to `firmware/bike_dashboard/bike_dashboard.ino`
  - States: READY → ACTIVE → PAUSED → ENDED
  - READY → ACTIVE: first pulse detected
  - ACTIVE → PAUSED: 30s no pulses (PAUSE_TIMEOUT_MS)
  - PAUSED → ACTIVE: pulse detected (resume)
  - PAUSED → ENDED: 2 min no pulses (END_TIMEOUT_MS)
- Active time tracking: accumulates intervals, excludes paused time
  - `accumulatedActiveMs` stores completed intervals, `activeStartTime` tracks current
- Color-coded status indicator: green PEDALING, yellow PAUSED, red ENDED, grey READY
- RPM timeout (3s) is separate from session pause (30s) — RPM zeroes faster
- Compiles: 335KB flash (25%), 23KB RAM (7%)

## 2026-02-24 - VB-009: Log session data to SD card

- Added SD card support to `firmware/bike_dashboard/bike_dashboard.ino`
  - SD card on VSPI bus (CS=IO5, MOSI=IO23, SCLK=IO18, MISO=IO19), separate from display HSPI
  - Graceful degradation: dashboard works without SD card, shows "SD" or "--" indicator
- Session files: `session_NNNN.csv` with auto-incrementing session numbers
  - Raw data: elapsed_sec, rpm, speed, distance, pulses — logged every 1s during session
  - Summary appended at end: duration, distance, avg/max RPM, avg/max speed, total revolutions
- Separate summary file: `summary_NNNN.csv` for easy parsing (field, unit, value format)
- Stats tracking: maxRpm, maxSpeed, sumRpm, rpmSampleCount for averages
- Status bar shows "SAVED" (red) when session ends and data is written
- Compiles: 381KB flash (29%), 23KB RAM (7%)
- Note: Uses sequential session numbers (not YYYY-MM-DD) — no RTC/WiFi yet

## 2026-02-24 - Phase 1 Complete!

- All 9 user stories (VB-001 through VB-009) are now passing
- Main production sketch: `firmware/bike_dashboard/bike_dashboard.ino`
- Capabilities: pulse counting, RPM smoothing, speed/distance, TFT dashboard, session management, SD logging

## 2026-02-25 - Phase 2 & 3: BLE Heart Rate + Token Tracking

- **VB-010:** Installed NimBLE-Arduino 2.3.7, created `firmware/test_ble_hr/test_ble_hr.ino`
  - Standalone BLE HR test: scans for H808S/CooSpo or HR Service UUID 0x180D
  - Connects, subscribes to HR Measurement (0x2A37), prints BPM to serial
  - Auto-reconnect on disconnect (restart scan)
  - Compiles: 602KB flash (45%), 36KB RAM (10%)
- **VB-011:** Integrated BLE HR into `bike_dashboard.ino`
  - NimBLE scan/connect runs in background (FreeRTOS task thread)
  - Notification callback updates `volatile currentHR` — same pattern as pulse ISR
  - `hrConnected` state flag, auto-reconnect via scan restart on disconnect
  - Parses HR measurement flags (8-bit vs 16-bit format)
- **VB-012:** Redesigned display — compact all-in-one layout
  - RPM: shrunk from font 7 to font 6 (saves ~50px vertical)
  - Speed/Distance row: labels + values + units (font 4)
  - Time/HR row: elapsed time + heart rate with bpm unit
  - Tokens/Cost row: session token delta + estimated cost (Phase 3)
  - Status bar: session state + revolution count
  - Status indicators: SD, WiFi (W), BLE (B) in title bar
- **VB-013:** Added HR to SD card logging
  - Raw data: `elapsed_sec,rpm,speed,distance,heart_rate,pulses`
  - Session summary: avg_hr, max_hr, min_hr fields added
  - HR=0 when strap not connected (doesn't skip logging)
- **VB-014:** WiFi setup on ESP32
  - Credentials via `WIFI_SSID`/`WIFI_PASSWORD` defines (leave empty to skip)
  - Connects at boot with 10s timeout, auto-reconnect every 30s
  - WiFi status indicator (W) in title bar — green/red
  - WiFi + BLE coexist via NimBLE radio time-slicing
- **VB-015:** Anthropic Usage API integration
  - Calls `GET /v1/organizations/usage` with Admin API key
  - WiFiClientSecure with HTTPS (insecure cert for personal project)
  - ArduinoJson 7.4.2 for response parsing
  - Tracks session token delta: baseline on first pedal, poll every 60s
  - Calculates estimated cost from input/output token pricing
- **VB-016:** Token display on dashboard
  - Session tokens with K/M suffix (e.g., "45.2K", "1.3M")
  - Estimated cost (e.g., "$1.87")
  - Grayed out when WiFi disconnected, "..." while loading
- **VB-017:** Combined session logging + docs update
  - tokens_used and estimated_cost added to session summary CSV
  - Updated CLAUDE.md: partition scheme, WiFi config, phase status
  - Updated docs/status.md, docs/worklog.md
- **Build notes:**
  - Partition scheme changed from default to `min_spiffs` (1.4MB / 1.9MB = 70%)
  - FQBN: `esp32:esp32:esp32:PartitionScheme=min_spiffs`
  - Total flash: 1390KB (70%), RAM: 60KB (18%)

## 2026-02-25 - Hardware testing & BLE debugging

- Uploaded firmware to board (460800 baud — 921600 causes chip crash)
- **NimBLE doesn't work on this board** — scan returns 0 devices, direct connect crashes
- Tested with built-in ESP32 BLE library — found 42+ devices including HR strap
- HR strap identified: "808S 0023713" at `de:5c:38:c5:83:1d`
- Rewrote test sketch and dashboard to use built-in ESP32 BLE (not NimBLE)
- Successfully receiving HR data: 89, 90, etc. bpm via BLE notifications
- Fixed RPM display: "RPM" label moved to right of number instead of below (per user feedback)
- Created `config.h` / `config.example.h` for WiFi/API credentials (gitignored)
- Created `.gitignore` for config.h, build artifacts, .DS_Store
- Created `scripts/test_api_key.sh` to verify Anthropic Admin API key

## 2026-02-27 - Pivot from Admin API to local stats server

- Discovered Admin API tracks API billing, not Claude Max subscription usage
- Found `~/.claude/stats-cache.json` contains local Claude Code usage stats (tokens, messages, sessions)
- Created `scripts/stats_server.py` — Python HTTP server that reads stats-cache.json and serves today's data
- Replaced Anthropic Admin API integration in firmware with local HTTP stats polling
- Removed `WiFiClientSecure` (HTTPS) — only need plain HTTP for local server, saves flash
- Changed display: TOKENS + MSGS (instead of TOKENS + COST, since Max has no per-token cost)
- Updated config.h: `STATS_SERVER_IP` + `STATS_SERVER_PORT` instead of `ANTHROPIC_ADMIN_KEY`
- Flash: 1855KB (94% of min_spiffs) — compiles successfully
- Updated CLAUDE.md, docs/status.md with BLE library switch and stats server approach

## 2026-03-01 - HR Zone feature (touch-enabled settings)

- Added touchscreen support using **XPT2046_Bitbang** library (software SPI, separate from display/SD buses)
  - Touch pins: MOSI=IO32, MISO=IO39, CLK=IO25, CS=IO33, IRQ=IO36
  - IRQ pin used for touch detection (LOW = touched), 300ms debounce
- Added page system: `PAGE_DASHBOARD` / `PAGE_HR_ZONE_SETTINGS`
  - Tap HR block on dashboard (right half, time/HR row) → opens settings page
  - Settings page: upper/lower limit +/- buttons (5 bpm steps), toggle on/off, back button
  - Limits: upper up to 220, lower down to 40, must maintain 5 bpm gap
- HR zone indicator on dashboard:
  - Green background on HR block when heart rate is in zone
  - Flashing red background when out of zone (500ms toggle)
  - HR label shows "120-160" range instead of "HR" when zone enabled
- NVS persistence via ESP32 Preferences library — zone settings survive reboots
- Created `firmware/test_touch/test_touch.ino` — standalone touch calibration/test sketch
- Flash: 1892KB (96% of min_spiffs) — ~6KB added, 74KB headroom remaining
- Test sketch: 358KB (27% of default partition)

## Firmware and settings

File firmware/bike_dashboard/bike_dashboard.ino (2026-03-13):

// bike_dashboard.ino — Vibe Bike Dashboard (VB-004 through VB-017)
// Pulse counter + speed/distance + TFT display + session auto-detect + SD logging
// + BLE heart rate (Phase 2) + WiFi Claude Code stats tracking (Phase 3).
//
// Board: ESP32-32E with ILI9341V (240x320)
// Wiring:
//   3.3V ─── 10K resistor ─── IO35 ─── bike wire 1
//   GND  ────────────────────────────── bike wire 2
//
// SD Card: VSPI bus (IO5=CS, IO23=MOSI, IO18=SCLK, IO19=MISO)
// Display: HSPI bus (IO15=CS, IO13=MOSI, IO14=SCLK, IO12=MISO)
//
// Build (min_spiffs partition needed for BLE+WiFi+HTTPS):
//   arduino-cli compile -b esp32:esp32:esp32:PartitionScheme=min_spiffs firmware/bike_dashboard
//   arduino-cli upload -b esp32:esp32:esp32:PartitionScheme=min_spiffs -p /dev/cu.usbmodem2101 firmware/bike_dashboard
//   arduino-cli monitor -p /dev/cu.usbmodem2101 -c baudrate=115200

#include <TFT_eSPI.h>
#include <SD.h>
#include <SPI.h>
#include <BLEDevice.h>
#include <BLEScan.h>
#include <BLEAdvertisedDevice.h>
#include <BLEClient.h>
#include <WiFi.h>
#include <HTTPClient.h>
#include <ArduinoJson.h>
#include <math.h>
#include <Preferences.h>
#include "config.h"  // WiFi + stats server + BLE config (copy config.example.h → config.h)

// Fallback for older config.h without BLE setting
#ifndef BLE_HR_DEVICE_NAME
#define BLE_HR_DEVICE_NAME  ""
#endif

// ── WiFi / Stats Settings ────────────────────────────────────
#define WIFI_TIMEOUT_MS   10000
#define STATS_POLL_INTERVAL_MS 30000  // Poll every 30 seconds

// ── Sensor Configuration ─────────────────────────────────────
#define SENSOR_PIN        35
#define DEBOUNCE_MS       50
#define RPM_TIMEOUT_MS    3000
#define MIN_RPM           10.0
#define MAX_RPM           200.0
#define SMOOTHING_SAMPLES 4

// ── Speed & Distance Configuration ───────────────────────────
#define DISTANCE_PER_REV_M  6.3
#define USE_METRIC          true
#define KM_TO_MILES         0.621371

// ── Session Configuration ────────────────────────────────────
#define PAUSE_TIMEOUT_MS    30000
#define END_TIMEOUT_MS      120000

// ── Display Configuration ────────────────────────────────────
#define TFT_BL_PIN        21
#define DISPLAY_UPDATE_MS 500

// ── Power Saving Configuration ───────────────────────────────
#define BOOT_BUTTON_PIN   0       // GPIO0 = physical BOOT button on board
#define BATTERY_ADC_PIN   34      // GPIO34 = battery voltage ADC (input-only)
#define SCREEN_DIM_MS     60000   // 60s inactivity → backlight off
#define SCREEN_SLEEP_MS   300000  // 5 min inactivity → ILI9341 sleep mode
#define BATT_READ_MS      30000   // Read battery every 30s
#define BATT_LOW_V        3.3     // Low battery threshold
#define BATT_CRITICAL_V   3.1     // Critical threshold
#define BATT_ADC_MULT     2.0     // Voltage divider ratio (calibrate after test)

// ── SD Card Configuration ────────────────────────────────────
#define SD_CS_PIN         5
#define RAW_LOG_INTERVAL_MS  1000

// ── Colors ───────────────────────────────────────────────────
#define BG_COLOR          TFT_BLACK
#define TITLE_COLOR       0x04B3
#define LABEL_COLOR       0x7BEF
#define RPM_COLOR         TFT_CYAN
#define SPEED_COLOR       TFT_GREEN
#define DIST_COLOR        TFT_YELLOW
#define TIME_COLOR        0xFD20
#define HR_COLOR          TFT_RED
#define TOKEN_COLOR       0xF81F    // Magenta
#define MSGS_COLOR        0x07FF    // Cyan-ish
#define DIVIDER_COLOR     0x2104
#define STATUS_ACTIVE     TFT_GREEN
#define STATUS_PAUSED     TFT_YELLOW
#define STATUS_ENDED      TFT_RED
#define STATUS_READY      0x7BEF
#define DIMMED_COLOR      0x4208    // Gray for disconnected values
#define HR_ZONE_IN_COLOR  0x0400    // Dark green background for in-zone
#define HR_ZONE_OUT_COLOR TFT_RED   // Red for out-of-zone flash
#define BUTTON_COLOR      0x4A69    // Gray button fill
#define BUTTON_TEXT_COLOR TFT_WHITE
#define TOGGLE_ON_COLOR   0x07E0    // Green
#define TOGGLE_OFF_COLOR  TFT_RED

// ── Touch Configuration (XPT2046 bit-bang SPI) ───────────────
#define TOUCH_MOSI  32
#define TOUCH_MISO  39
#define TOUCH_CLK   25
#define TOUCH_CS    33
#define TOUCH_IRQ   36
#define TOUCH_DEBOUNCE_MS 300
// Calibration from raw diagnostic (raw ADC → screen pixels)
#define TOUCH_RAW_X_MIN  185
#define TOUCH_RAW_X_MAX  1770
#define TOUCH_RAW_Y_MIN  150
#define TOUCH_RAW_Y_MAX  1840
#define TOUCH_PRESSURE_MIN 50  // Z1 threshold for real touch

// ── Page State ───────────────────────────────────────────────
enum PageState {
    PAGE_DASHBOARD,
    PAGE_HR_ZONE_SETTINGS
};

// ── Compact Layout (240x320 portrait) ────────────────────────
// Title bar
#define TITLE_Y       4
// RPM section (value centered, "RPM" label drawn to the right dynamically)
#define RPM_VALUE_Y   28
// Divider 1
#define DIV1_Y        80
// Speed / Distance row (block: 80–168, 88px)
#define SPEED_LABEL_Y 82       // flush top: DIV1+2
#define SPEED_VALUE_Y 111      // centered: 98+(52-26)/2
#define SPEED_UNIT_Y  150      // flush bottom: DIV2-16-2
#define DIST_LABEL_Y  82
#define DIST_VALUE_Y  111
#define DIST_UNIT_Y   150
// Divider 2
#define DIV2_Y        168
// Time / HR row (block: 168–246, 78px)
#define TIME_LABEL_Y  170      // flush top: DIV2+2
#define TIME_VALUE_Y  194      // centered: 186+(42-26)/2
#define HR_LABEL_Y    170
#define HR_VALUE_Y    194
#define HR_UNIT_Y     228      // flush bottom: DIV3-16-2
// Divider 3
#define DIV3_Y        246
// Tokens / Messages row (block: 246–294, 48px)
#define TOKEN_LABEL_Y 248      // flush top: DIV3+2
#define TOKEN_VALUE_Y 266      // centered: 264+(30-26)/2
#define MSGS_LABEL_Y  248
#define MSGS_VALUE_Y  266
// Divider 4
#define DIV4_Y        294
// Status bar
#define STATUS_Y      302
// Columns
#define LEFT_COL      60
#define RIGHT_COL     180

TFT_eSPI tft = TFT_eSPI();
Preferences prefs;

// ── Page & Touch State ───────────────────────────────────────
PageState currentPage = PAGE_DASHBOARD;
unsigned long lastTouchTime = 0;

// ── HR Zone State ────────────────────────────────────────────
bool hrZoneEnabled = false;
uint16_t hrZoneUpper = 160;
uint16_t hrZoneLower = 120;
bool hrZoneFlashState = false;        // Toggles for out-of-zone flash
unsigned long lastZoneFlashTime = 0;

// ── Session States ───────────────────────────────────────────
enum SessionState {
    SESSION_READY,
    SESSION_ACTIVE,
    SESSION_PAUSED,
    SESSION_ENDED
};

// ── ISR Variables ────────────────────────────────────────────
volatile unsigned long lastPulseTime = 0;
volatile unsigned long pulseInterval = 0;
volatile unsigned long pulseCount = 0;
volatile bool newPulse = false;

void IRAM_ATTR onPulse() {
    unsigned long now = millis();
    unsigned long elapsed = now - lastPulseTime;
    if (elapsed > DEBOUNCE_MS) {
        pulseInterval = elapsed;
        lastPulseTime = now;
        pulseCount++;
        newPulse = true;
    }
}

// ── RPM Smoothing ────────────────────────────────────────────
float rpmBuffer[SMOOTHING_SAMPLES];
int rpmBufferIndex = 0;
bool rpmBufferFull = false;

void addRpmSample(float rpm) {
    rpmBuffer[rpmBufferIndex] = rpm;
    rpmBufferIndex = (rpmBufferIndex + 1) % SMOOTHING_SAMPLES;
    if (rpmBufferIndex == 0) rpmBufferFull = true;
}

float getSmoothedRpm() {
    int count = rpmBufferFull ? SMOOTHING_SAMPLES : rpmBufferIndex;
    if (count == 0) return 0.0;
    float sum = 0;
    for (int i = 0; i < count; i++) sum += rpmBuffer[i];
    return sum / count;
}

void clearRpmBuffer() {
    for (int i = 0; i < SMOOTHING_SAMPLES; i++) rpmBuffer[i] = 0;
    rpmBufferIndex = 0;
    rpmBufferFull = false;
}

// ── State ────────────────────────────────────────────────────
float currentRpm = 0;
float smoothedRpm = 0;
float currentSpeed = 0;
float totalDistanceM = 0;
unsigned long lastDistancePulse = 0;
unsigned long displayPulseCount = 0;
unsigned long lastDisplayUpdate = 0;

// Session state
SessionState sessionState = SESSION_READY;
unsigned long activeStartTime = 0;
unsigned long accumulatedActiveMs = 0;
unsigned long lastPulseTimeLoop = 0;

// Session stats (for summary)
float maxRpm = 0;
float maxSpeed = 0;
double sumRpm = 0;
unsigned long rpmSampleCount = 0;

// SD card state
bool sdReady = false;
int sessionNumber = 0;
char sessionFilename[24];
unsigned long lastRawLogTime = 0;
bool sessionLogged = false;

// ── BLE Heart Rate State ─────────────────────────────────────
static BLEUUID hrServiceUUID("180D");
static BLEUUID hrCharUUID("2A37");
static BLEClient* pBLEClient = nullptr;
static volatile uint16_t currentHR = 0;
static volatile bool hrConnected = false;
static bool bleDoConnect = false;
static BLEAdvertisedDevice* bleTargetDevice = nullptr;
static unsigned long lastBleScanTime = 0;

// HR session stats
uint16_t maxHR = 0;
uint16_t minHR = 0;    // Min non-zero HR during session
double sumHR = 0;
unsigned long hrSampleCount = 0;

// ── WiFi & Stats State ───────────────────────────────────────
bool wifiEnabled = false;
bool wifiConnected = false;
bool statsTrackingEnabled = false;
unsigned long lastStatsPollTime = 0;

// Stats from Claude Code (via local stats server)
unsigned long sessionStartTokens = 0;
unsigned long sessionStartUserMsgs = 0;
unsigned long sessionStartAsstMsgs = 0;
unsigned long latestTokens = 0;
unsigned long latestUserMsgs = 0;
unsigned long latestAsstMsgs = 0;
unsigned long sessionTokensDelta = 0;
unsigned long sessionUserMsgsDelta = 0;
unsigned long sessionAsstMsgsDelta = 0;
unsigned long todayTokens = 0;
unsigned long todayUserMsgs = 0;
unsigned long todayAsstMsgs = 0;
bool statsDataValid = false;
bool initialStatsFetchDone = false;

// Previous display values (for dirty-region updates)
int prevRpmInt = -1;
int prevSpeedTenths = -1;
int prevDistHundredths = -1;
int prevTimeSec = -1;
int prevHR = -1;
bool prevHRConnected = false;
long prevTokensK = -1;
long prevUserMsgs = -1;
long prevAsstMsgs = -1;
SessionState prevDisplayState = SESSION_READY;
unsigned long prevDisplayPulses = 0;
bool firstDraw = true;

// ── Power Saving State ──────────────────────────────────────
bool screenOn = true;
bool displaySleeping = false;
unsigned long lastActivityTime = 0;
unsigned long lastBootButtonTime = 0;
float batteryVoltage = 0;
bool batteryLow = false;
bool batteryCritical = false;
bool batteryAvailable = false;
unsigned long lastBattReadTime = 0;
unsigned long lastBattReadDone = 0;  // suppress touch after ADC read
int prevBattIcon = -1;  // dirty-region tracker: -1=not drawn, 0=hidden, 1=low, 2=critical

// ── Helpers ──────────────────────────────────────────────────
float rpmToSpeed(float rpm) {
    float speedKmh = rpm * DISTANCE_PER_REV_M * 60.0 / 1000.0;
    return USE_METRIC ? speedKmh : speedKmh * KM_TO_MILES;
}

float getDisplayDistance() {
    float distKm = totalDistanceM / 1000.0;
    return USE_METRIC ? distKm : distKm * KM_TO_MILES;
}

const char* speedUnit() { return USE_METRIC ? "km/h" : "mph"; }
const char* distUnit()  { return USE_METRIC ? "km"   : "mi"; }

unsigned long getActiveTimeMs(unsigned long now) {
    if (sessionState == SESSION_ACTIVE) {
        return accumulatedActiveMs + (now - activeStartTime);
    }
    return accumulatedActiveMs;
}

// ── BLE Heart Rate (built-in ESP32 BLE) ──────────────────────

// Notification callback
static void hrNotifyCallback(BLERemoteCharacteristic* pChar,
                             uint8_t* pData, size_t length, bool isNotify) {
    if (length < 2) return;

    uint16_t hr;
    if (pData[0] & 0x01) {
        hr = (length >= 3) ? (pData[1] | (pData[2] << 8)) : pData[1];
    } else {
        hr = pData[1];
    }

    currentHR = hr;
}

class HRClientCallbacks : public BLEClientCallbacks {
    void onConnect(BLEClient* pClient) override {
        hrConnected = true;
        Serial.println("BLE: Connected to HR strap");
    }
    void onDisconnect(BLEClient* pClient) override {
        hrConnected = false;
        currentHR = 0;
        Serial.println("BLE: HR strap disconnected");
    }
};

class HRScanCallbacks : public BLEAdvertisedDeviceCallbacks {
    void onResult(BLEAdvertisedDevice advertisedDevice) override {
        String name = String(advertisedDevice.getName().c_str());
        bool hasHRService = advertisedDevice.haveServiceUUID() &&
                            advertisedDevice.isAdvertisingService(hrServiceUUID);

        bool nameMatch = (strlen(BLE_HR_DEVICE_NAME) > 0) ?
                          (name.indexOf(BLE_HR_DEVICE_NAME) >= 0) : false;

        if (hasHRService || nameMatch) {
            Serial.printf("BLE: Found HR device: %s [%s]\n",
                          name.c_str(),
                          advertisedDevice.getAddress().toString().c_str());
            advertisedDevice.getScan()->stop();
            bleTargetDevice = new BLEAdvertisedDevice(advertisedDevice);
            bleDoConnect = true;
        }
    }
};

bool connectToHR() {
    if (!bleTargetDevice) return false;

    pBLEClient = BLEDevice::createClient();
    pBLEClient->setClientCallbacks(new HRClientCallbacks());

    Serial.printf("BLE: Connecting to %s...\n",
                  bleTargetDevice->getAddress().toString().c_str());

    if (!pBLEClient->connect(bleTargetDevice)) {
        Serial.println("BLE: Connection failed");
        return false;
    }

    BLERemoteService* pService = pBLEClient->getService(hrServiceUUID);
    if (!pService) {
        Serial.println("BLE: HR service not found");
        pBLEClient->disconnect();
        return false;
    }

    BLERemoteCharacteristic* pChar = pService->getCharacteristic(hrCharUUID);
    if (!pChar) {
        Serial.println("BLE: HR characteristic not found");
        pBLEClient->disconnect();
        return false;
    }

    if (pChar->canNotify()) {
        pChar->registerForNotify(hrNotifyCallback);
        Serial.println("BLE: Subscribed to HR notifications");
    } else {
        Serial.println("BLE: Characteristic doesn't support notify");
        pBLEClient->disconnect();
        return false;
    }

    return true;
}

static HRScanCallbacks hrScanCB;
static bool bleScanActive = false;

void initBLE() {
    BLEDevice::init("VibeBike");

    BLEScan* pScan = BLEDevice::getScan();
    pScan->setAdvertisedDeviceCallbacks(&hrScanCB, false);
    pScan->setActiveScan(true);
    pScan->setInterval(100);
    pScan->setWindow(99);

    Serial.println("BLE: Starting scan for HR devices...");
    pScan->start(0, nullptr, false);  // Continuous background scan
    bleScanActive = true;
}

void handleBLE() {
    // Handle pending connection from scan callback
    if (bleDoConnect) {
        bleDoConnect = false;

        BLEDevice::getScan()->stop();
        bleScanActive = false;

        if (connectToHR()) {
            delete bleTargetDevice;
            bleTargetDevice = nullptr;
            return;
        }
        delete bleTargetDevice;
        bleTargetDevice = nullptr;
    }

    // Restart scan if not connected and scan not running
    if (!hrConnected && !bleDoConnect && !bleScanActive) {
        unsigned long now = millis();
        if (now - lastBleScanTime > 5000) {
            lastBleScanTime = now;
            Serial.println("BLE: Restarting scan...");
            BLEScan* pScan = BLEDevice::getScan();
            pScan->clearResults();
            pScan->start(0, nullptr, false);
            bleScanActive = true;
        }
    }
}

// ── WiFi Functions ───────────────────────────────────────────

void initWiFi() {
    if (strlen(WIFI_SSID) == 0) {
        Serial.println("WiFi: No SSID configured, skipping");
        return;
    }

    wifiEnabled = true;
    WiFi.mode(WIFI_STA);
    WiFi.begin(WIFI_SSID, WIFI_PASSWORD);

    Serial.printf("WiFi: Connecting to %s", WIFI_SSID);
    unsigned long start = millis();
    while (WiFi.status() != WL_CONNECTED && millis() - start < WIFI_TIMEOUT_MS) {
        delay(250);
        Serial.print(".");
    }
    Serial.println();

    if (WiFi.status() == WL_CONNECTED) {
        wifiConnected = true;
        Serial.printf("WiFi: Connected! IP: %s\n", WiFi.localIP().toString().c_str());
    } else {
        Serial.println("WiFi: Connection failed (will retry in background)");
    }

    // Enable stats tracking if server IP is set
    if (strlen(STATS_SERVER_IP) > 0) {
        statsTrackingEnabled = true;
        Serial.printf("WiFi: Stats tracking enabled (server: %s:%d)\n",
                      STATS_SERVER_IP, STATS_SERVER_PORT);
    }
}

void handleWiFi() {
    if (!wifiEnabled) return;

    bool nowConnected = (WiFi.status() == WL_CONNECTED);
    if (nowConnected != wifiConnected) {
        wifiConnected = nowConnected;
        if (wifiConnected) {
            Serial.println("WiFi: Reconnected");
        } else {
            Serial.println("WiFi: Disconnected");
        }
    }

    // Reconnect if needed
    if (!wifiConnected) {
        static unsigned long lastReconnectAttempt = 0;
        if (millis() - lastReconnectAttempt > 30000) {
            lastReconnectAttempt = millis();
            WiFi.disconnect();
            WiFi.begin(WIFI_SSID, WIFI_PASSWORD);
        }
    }
}

// ── Claude Code Stats (via local HTTP server) ────────────────

bool fetchStats(unsigned long* outTokens, unsigned long* outUserMsgs, unsigned long* outAsstMsgs) {
    if (!wifiConnected || !statsTrackingEnabled) return false;

    HTTPClient http;

    char url[128];
    snprintf(url, sizeof(url), "http://%s:%d/stats", STATS_SERVER_IP, STATS_SERVER_PORT);

    http.begin(url);
    http.setTimeout(5000);

    int httpCode = http.GET();

    if (httpCode != 200) {
        Serial.printf("Stats: HTTP %d\n", httpCode);
        http.end();
        return false;
    }

    String payload = http.getString();
    http.end();

    // Parse JSON: {"date":"...","userMessages":N,"assistantMessages":N,"sessions":N,"toolCalls":N,"outputTokens":N}
    JsonDocument doc;
    DeserializationError err = deserializeJson(doc, payload);
    if (err) {
        Serial.printf("Stats: JSON error: %s\n", err.c_str());
        return false;
    }

    *outTokens = doc["outputTokens"] | 0UL;
    *outUserMsgs = doc["userMessages"] | 0UL;
    *outAsstMsgs = doc["assistantMessages"] | 0UL;

    Serial.printf("Stats: tokens=%lu userMsgs=%lu asstMsgs=%lu\n", *outTokens, *outUserMsgs, *outAsstMsgs);
    return true;
}
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
void loop() {
    unsigned long now = millis();
    bool gotPulse = false;

    // Process new pulse from ISR
    if (newPulse) {
        newPulse = false;
        gotPulse = true;
        updateActivity();

        noInterrupts();
        unsigned long interval = pulseInterval;
        unsigned long count = pulseCount;
        interrupts();

        displayPulseCount = count;

        if (interval > 0) {
            currentRpm = 60000.0 / interval;
        }

        if (currentRpm < MIN_RPM) {
            currentRpm = 0;
        } else if (currentRpm > MAX_RPM) {
            currentRpm = 0;  // Ignore spurious high-RPM readings (sensor bounce)
        }

        if (currentRpm > 0) {
            addRpmSample(currentRpm);
        }

        unsigned long newPulses = count - lastDistancePulse;
        if (newPulses > 0 && currentRpm >= MIN_RPM) {
            totalDistanceM += newPulses * DISTANCE_PER_REV_M;
            lastDistancePulse = count;
        }
    }

    // Read last pulse time for state machine
    noInterrupts();
    unsigned long timeSinceLastPulse = now - lastPulseTime;
    lastPulseTimeLoop = lastPulseTime;
    interrupts();

    // RPM timeout
    if (lastPulseTimeLoop > 0 && timeSinceLastPulse > RPM_TIMEOUT_MS) {
        currentRpm = 0;
        clearRpmBuffer();
    }

    // Session state machine
    updateSessionState(now, timeSinceLastPulse, gotPulse);

    // Calculate values
    smoothedRpm = (currentRpm > 0) ? getSmoothedRpm() : 0;
    currentSpeed = rpmToSpeed(smoothedRpm);

    // Track session stats (only when actively pedaling)
    if (sessionState == SESSION_ACTIVE && smoothedRpm > 0) {
        sumRpm += smoothedRpm;
        rpmSampleCount++;
        if (smoothedRpm > maxRpm) maxRpm = smoothedRpm;
        if (currentSpeed > maxSpeed) maxSpeed = currentSpeed;
    }

    // Track HR stats during active session
    uint16_t hr = currentHR;
    if (sessionState == SESSION_ACTIVE && hr > 0) {
        sumHR += hr;
        hrSampleCount++;
        if (hr > maxHR) maxHR = hr;
        if (minHR == 0 || hr < minHR) minHR = hr;
    }

    // Handle BLE (connection management)
    handleBLE();

    // Handle WiFi (reconnection)
    handleWiFi();

    // Handle stats tracking (local server polling)
    handleStatsTracking(now);

    // Handle touch input (skip when screen off — wake via pedal/BOOT only;
    // skip briefly after battery ADC read — GPIO34 crosstalk glitches GPIO36/TOUCH_IRQ)
    if (screenOn && !displaySleeping && millis() - lastBattReadDone > 50) {
        int tx, ty;
        if (readTouch(&tx, &ty)) {
            updateActivity();
            handleTouch(tx, ty);
        }
    }

    // Raw data logging to SD
    if (sdReady && (sessionState == SESSION_ACTIVE || sessionState == SESSION_PAUSED)) {
        if (now - lastRawLogTime >= RAW_LOG_INTERVAL_MS) {
            lastRawLogTime = now;
            logRawData(getActiveTimeMs(now));
        }
    }

    // Power saving (screen dim/sleep, battery, BOOT button)
    handlePowerSaving(now);

    // Update display at fixed interval (only on dashboard page, only when screen on)
    if (screenOn && currentPage == PAGE_DASHBOARD && now - lastDisplayUpdate >= DISPLAY_UPDATE_MS) {
        lastDisplayUpdate = now;

        updateRpmDisplay(smoothedRpm);
        updateSpeedDisplay(currentSpeed);
        updateDistDisplay(getDisplayDistance());
        updateTimeDisplay(getActiveTimeMs(now));
        updateHRDisplay(hr);
        updateTokenDisplay();
        updateStatusBar(sessionState, displayPulseCount);
        updateBLEIndicator();
        updateWiFiIndicator();
        drawBatteryIcon();
    }
}

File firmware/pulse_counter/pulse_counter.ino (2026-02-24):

// Vibe Bike — Pulse Counter + Speed/Distance Firmware (VB-004, VB-005)
// Interrupt-driven cadence, speed, and distance from bike reed switch.
//
// Wiring:
//   3.3V ─── 10K resistor ─── IO35 ─── bike wire 1
//   GND  ────────────────────────────── bike wire 2
//
// Reed switch: HIGH at rest, LOW pulse on magnet pass (1 pulse/revolution).
//
// Compile & upload:
//   arduino-cli compile -b esp32:esp32:esp32 firmware/pulse_counter
//   arduino-cli upload -b esp32:esp32:esp32 -p /dev/cu.usbmodem2101 firmware/pulse_counter
//   arduino-cli monitor -p /dev/cu.usbmodem2101 -c baudrate=115200

// ── Configuration ──────────────────────────────────────────────
#define SENSOR_PIN        35      // IO35 (input-only), external 10K pull-up
#define DEBOUNCE_MS       50      // Ignore pulses within this window (reed bounce)
#define RPM_TIMEOUT_MS    3000    // No pulse for this long → RPM = 0 (stopped)
#define MIN_RPM           10.0    // Below this, consider noise / stopped
#define MAX_RPM           200.0   // Above this, likely bounce artifact
#define SMOOTHING_SAMPLES 4       // Rolling average window for RPM
#define SERIAL_UPDATE_MS  500     // How often to print RPM to serial

// ── Speed & Distance Configuration ─────────────────────────────
// Indoor bike: 1 reed switch pulse = 1 pedal revolution.
// DISTANCE_PER_REV estimates the road-equivalent distance per pedal revolution.
// Typical indoor bike with ~3:1 flywheel ratio and 700c equivalent:
//   1 pedal rev × 3 wheel revs × 2.1m circumference ≈ 6.3m
// Adjust this value to calibrate your specific bike.
#define DISTANCE_PER_REV_M  6.3   // Meters of road-equivalent distance per revolution
#define USE_METRIC          true  // true = km/h + km, false = mph + miles
#define KM_TO_MILES         0.621371

// ── ISR Variables (volatile, accessed from interrupt) ──────────
volatile unsigned long lastPulseTime = 0;
volatile unsigned long pulseInterval = 0;
volatile unsigned long pulseCount = 0;
volatile bool newPulse = false;

// ── ISR ────────────────────────────────────────────────────────
void IRAM_ATTR onPulse() {
    unsigned long now = millis();
    unsigned long elapsed = now - lastPulseTime;

    if (elapsed > DEBOUNCE_MS) {
        pulseInterval = elapsed;
        lastPulseTime = now;
        pulseCount++;
        newPulse = true;
    }
}

// ── RPM Smoothing Buffer ──────────────────────────────────────
float rpmBuffer[SMOOTHING_SAMPLES];
int rpmBufferIndex = 0;
bool rpmBufferFull = false;

void addRpmSample(float rpm) {
    rpmBuffer[rpmBufferIndex] = rpm;
    rpmBufferIndex = (rpmBufferIndex + 1) % SMOOTHING_SAMPLES;
    if (rpmBufferIndex == 0) rpmBufferFull = true;
}

float getSmoothedRpm() {
    int count = rpmBufferFull ? SMOOTHING_SAMPLES : rpmBufferIndex;
    if (count == 0) return 0.0;

    float sum = 0;
    for (int i = 0; i < count; i++) {
        sum += rpmBuffer[i];
    }
    return sum / count;
}

void clearRpmBuffer() {
    for (int i = 0; i < SMOOTHING_SAMPLES; i++) rpmBuffer[i] = 0;
    rpmBufferIndex = 0;
    rpmBufferFull = false;
}

// ── State ─────────────────────────────────────────────────────
float currentRpm = 0;
float smoothedRpm = 0;
unsigned long lastSerialUpdate = 0;
unsigned long displayPulseCount = 0;

// ── Speed & Distance State ───────────────────────────────────
float currentSpeed = 0;          // Current speed in display units (km/h or mph)
float totalDistanceM = 0;        // Accumulated distance in meters
unsigned long lastDistancePulse = 0;  // Last pulse count used for distance calc

// ── Speed & Distance Helpers ─────────────────────────────────
// Convert RPM to speed in display units
float rpmToSpeed(float rpm) {
    // speed = RPM × distance_per_rev × 60 min/hr ÷ 1000 m/km
    float speedKmh = rpm * DISTANCE_PER_REV_M * 60.0 / 1000.0;
    return USE_METRIC ? speedKmh : speedKmh * KM_TO_MILES;
}

// Get total distance in display units
float getDisplayDistance() {
    float distKm = totalDistanceM / 1000.0;
    return USE_METRIC ? distKm : distKm * KM_TO_MILES;
}

const char* speedUnit() { return USE_METRIC ? "km/h" : "mph"; }
const char* distUnit()  { return USE_METRIC ? "km"   : "mi"; }

// ── Setup ─────────────────────────────────────────────────────
void setup() {
    Serial.begin(115200);
    delay(100);

    pinMode(SENSOR_PIN, INPUT);  // External 10K pull-up to 3.3V
    attachInterrupt(digitalPinToInterrupt(SENSOR_PIN), onPulse, FALLING);

    clearRpmBuffer();

    Serial.println();
    Serial.println("╔══════════════════════════════════════╗");
    Serial.println("║   Vibe Bike — Pulse + Speed/Distance ║");
    Serial.println("║   Firmware v1.1 (VB-004 + VB-005)   ║");
    Serial.println("╠══════════════════════════════════════╣");
    Serial.printf( "║ Sensor: IO35 (FALLING interrupt)     ║\n");
    Serial.printf( "║ Distance/rev: %.1f m                  ║\n", DISTANCE_PER_REV_M);
    Serial.printf( "║ Units: %s, %s                    ║\n", speedUnit(), distUnit());
    Serial.println("║ Debounce: 50ms | Timeout: 3s         ║");
    Serial.println("╚══════════════════════════════════════╝");
    Serial.println();
    Serial.println("Waiting for pedaling...");
    Serial.println();
}
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

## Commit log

2026-02-24 Initial project setup: PRD, docs, and test firmware
    Vibe Bike Phase 1 project scaffolding with planning docs,
    reed switch test sketches, and build conventions.
2026-02-24 feat: VB-004 - Implement pulse counter firmware
    Interrupt-driven cadence measurement from bike reed switch on IO35.
    Features: 50ms debounce, 3s stopped timeout, RPM clamping (10-200),
    4-sample rolling average smoothing, and 2Hz serial output.
2026-02-24 feat: VB-006 - Set up Arduino CLI project and display Hello World
2026-02-26 feat: VB-010 to VB-017 - Phase 2 (BLE heart rate) and Phase 3 (WiFi token tracking)
    Add BLE heart rate monitoring via NimBLE-Arduino connecting to Coospo H808S
    chest strap, WiFi with Anthropic Usage API integration for live token tracking,
    and a redesigned compact display layout showing RPM, speed, distance, time,
    heart rate, tokens, and cost all on the 240x320 TFT.
    Phase 2 changes:
    - NimBLE-Arduino 2.3.7 for BLE client (scan, connect, auto-reconnect)
    - Standalone test sketch: firmware/test_ble_hr/test_ble_hr.ino
    - HR notification callback with 8/16-bit format parsing
    - HR stats in SD card logging (avg/max/min)
    Phase 3 changes:
    - WiFi connection with auto-reconnect (credentials via defines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
    [bike_dashboard.ino, test_ble_hr.ino]
2026-03-01 feat: 3D printable display mount and front cap
    Mount v4.1: tray-style case for ES3C28P board (50x86mm) that slides
    onto bike's metal plate bracket. Friction-fit board cavity, 4 L-bracket
    corner spacers for battery space, USB-C slot on bottom.
    Front cap: snap-on faceplate with screen cutout (43.6x58mm visible area)
    and wrap-around lip for alignment.
    [bike_mount.scad, bike_mount.stl, front_cap.scad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]
2026-03-01 feat: touchscreen HR zone settings with border indicator
    Add XPT2046 touch support (raw bit-bang SPI, interrupt-protected) to
    enable HR zone configuration directly on the display. Tap the HR block
    to open settings page with +/- buttons for upper/lower limits, on/off
    toggle. Zone indicator shows colored border (green=in zone, flashing
    red=out of zone). Settings persist across reboots via ESP32 NVS.
    [bike_dashboard.ino, test_touch.ino]
2026-03-05 Add LICENSE (MIT), 3D model renders, stats server, and remaining files for public release
    [bike_mount.scad, bike_mount.stl, front_cap.scad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]
2026-03-13 fix: timer freeze bug, distance clipping, split user/AI message counts
    - Fix session timer freezing: spurious high-RPM pulses caused early return
    from loop(), preventing session state machine from resuming after pause
    - Fix distance display clipping past screen edge by removing width padding
    and adding proper clear-before-draw
    - Vertically align UI blocks: labels flush top, units flush bottom, values
    centered
    - Split message count into user/assistant (shown as "USR/AI: 12/38")
    in both firmware display and stats server API
    [bike_dashboard.ino]
